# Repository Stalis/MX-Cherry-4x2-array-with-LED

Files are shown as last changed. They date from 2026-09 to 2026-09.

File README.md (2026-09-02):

# MX Cherry 4x2

## PCB Renders

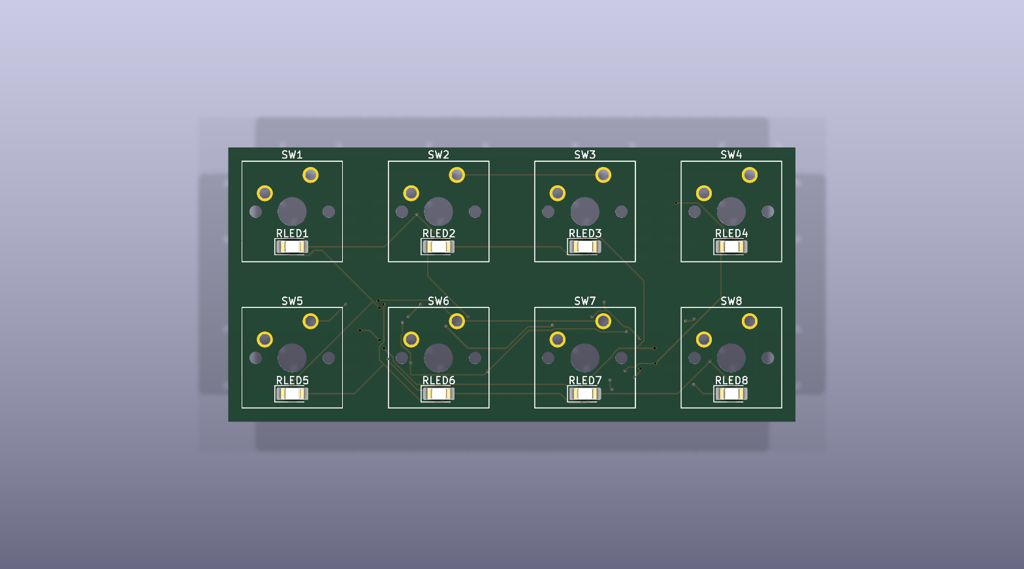
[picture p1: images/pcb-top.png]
Top-side PCB render

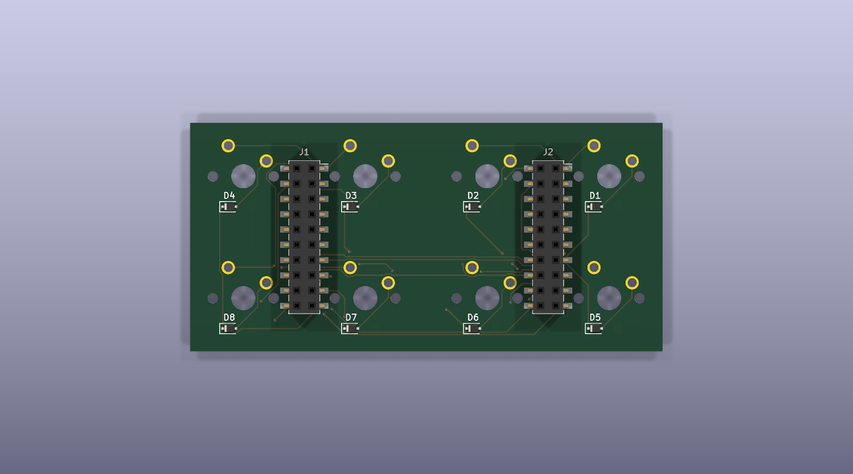
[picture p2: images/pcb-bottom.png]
Bottom-side PCB render


Compact 8-key Cherry MX keyboard module: 4 columns x 2 rows. It has no onboard microcontroller and is intended for connection to an external controller or breadboard.

## Features

- 8 Cherry MX 1U, PCB-mount switch footprints on a 19.05 mm pitch.
- 4x2 switch matrix with one diode per key.
- Independent 4x2 LED matrix with one LED per key.
- Two parallel SMD socket connectors, `J1` and `J2`: 2x10, 2.54 mm pitch, on the bottom side of the board.
- Two-layer, 1.6 mm thick PCB measuring 78.74 x 38.10 mm.

## Matrices

Key layout:

| | `COL_0` | `COL_1` | `COL_2` | `COL_3` |
| --- | --- | --- | --- | --- |
| `ROW_0` | SW1 / D1 / RLED1 | SW2 / D2 / RLED2 | SW3 / D3 / RLED3 | SW4 / D4 / RLED4 |
| `ROW_1` | SW5 / D5 / RLED5 | SW6 / D6 / RLED6 | SW7 / D7 / RLED7 | SW8 / D8 / RLED8 |

Each key has a series diode, `D1` through `D8`, to prevent ghosting during matrix scanning. LEDs `RLED1` through `RLED8` form an independent matrix with the same four columns and two rows.

## Connections

`J1` and `J2` are electrically identical: use either connector, or both to mount the module. Pin numbering follows the standard 2x10 connector convention: odd pins are on one row and even pins on the other.

| Pin | Signal | Function |
| --- | --- | --- |
| 1 | `SW_0_ROW_0` | switch-matrix row 0 |
| 2 | `LED_0_ROW_0` | LED-matrix row 0 |
| 3 | `SW_0_ROW_1` | switch-matrix row 1 |
| 4 | `LED_0_ROW_1` | LED-matrix row 1 |
| 5-12 | NC | not connected |
| 13 | `SW_0_COL_0` | switch-matrix column 0 |
| 14 | `LED_0_COL_0` | LED-matrix column 0 |
| 15 | `SW_0_COL_1` | switch-matrix column 1 |
| 16 | `LED_0_COL_1` | LED-matrix column 1 |
| 17 | `SW_0_COL_2` | switch-matrix column 2 |
| 18 | `LED_0_COL_2` | LED-matrix column 2 |
| 19 | `SW_0_COL_3` | switch-matrix column 3 |
| 20 | `LED_0_COL_3` | LED-matrix column 3 |

The controller must scan both matrices externally. The PCB has no LED current-limiting resistors; use an external current-limiting circuit or LED driver.

## Components

| Quantity | References | Footprint |
| --- | --- | --- |
| 8 | `SW1-SW8` | Cherry MX 1U, PCB mount |
| 8 | `D1-D8` | SOD-323F |
| 8 | `RLED1-RLED8` | LED 1206, 3216 Metric |
| 2 | `J1`, `J2` | SMD socket 2x10, 2.54 mm |

The schematic does not specify diode ratings or LED color and electrical parameters. Select them for the voltage and current of the external driver.

## DRC Notes

The following DRC findings are expected for this layout and should be excluded individually with a comment in KiCad after mechanical clearance is confirmed. Do not disable these checks globally.

| DRC check | Count | Rationale |
| --- | --- | --- |
| `npth_inside_courtyard` | 8 | The Cherry MX locating holes are through-holes, while `J1` and `J2` are bottom-side SMD connectors. The overlaps are courtyard-only; verify the connector body and pads clear the switch locating pins. |
| `courtyards_overlap` | 8 | Each top-side LED is intentionally placed at its associated switch for backlighting. |
| `footprint_symbol_field_mismatch` | 8 warnings | Diodes `D1-D8` have a schematic-only `Sim.Device` field that is absent from their footprints. This does not affect fabrication or electrical connectivity. |

## Repository Files

- `MX Cherry 4x2.kicad_pro` - KiCad project.
- `MX Cherry 4x2.kicad_sch` - main schematic.
- `MX Cherry 4x2.kicad_pcb` - PCB layout.
- `switch_module.kicad_sch` and `led_module.kicad_sch` - reusable sheets for one switch with a diode and one LED.
- `jlcpcb/` and `production/` - previously exported manufacturing files.

> The BOM and CPL files in `jlcpcb/` and `production/` are outdated relative to the current schematic and PCB. They omit `RLED1` through `RLED8` and describe the connectors as 1x10. Re-export Gerbers, BOM, and CPL from the current project before ordering.

## Opening and Checking

The project was created with KiCad 10. Open `MX Cherry 4x2.kicad_pro` in KiCad, or check it from the command line:

```sh
/Applications/KiCad/KiCad.app/Contents/MacOS/kicad-cli sch erc "MX Cherry 4x2.kicad_sch"
/Applications/KiCad/KiCad.app/Contents/MacOS/kicad-cli pcb drc --schematic-parity "MX Cherry 4x2.kicad_pcb"
```

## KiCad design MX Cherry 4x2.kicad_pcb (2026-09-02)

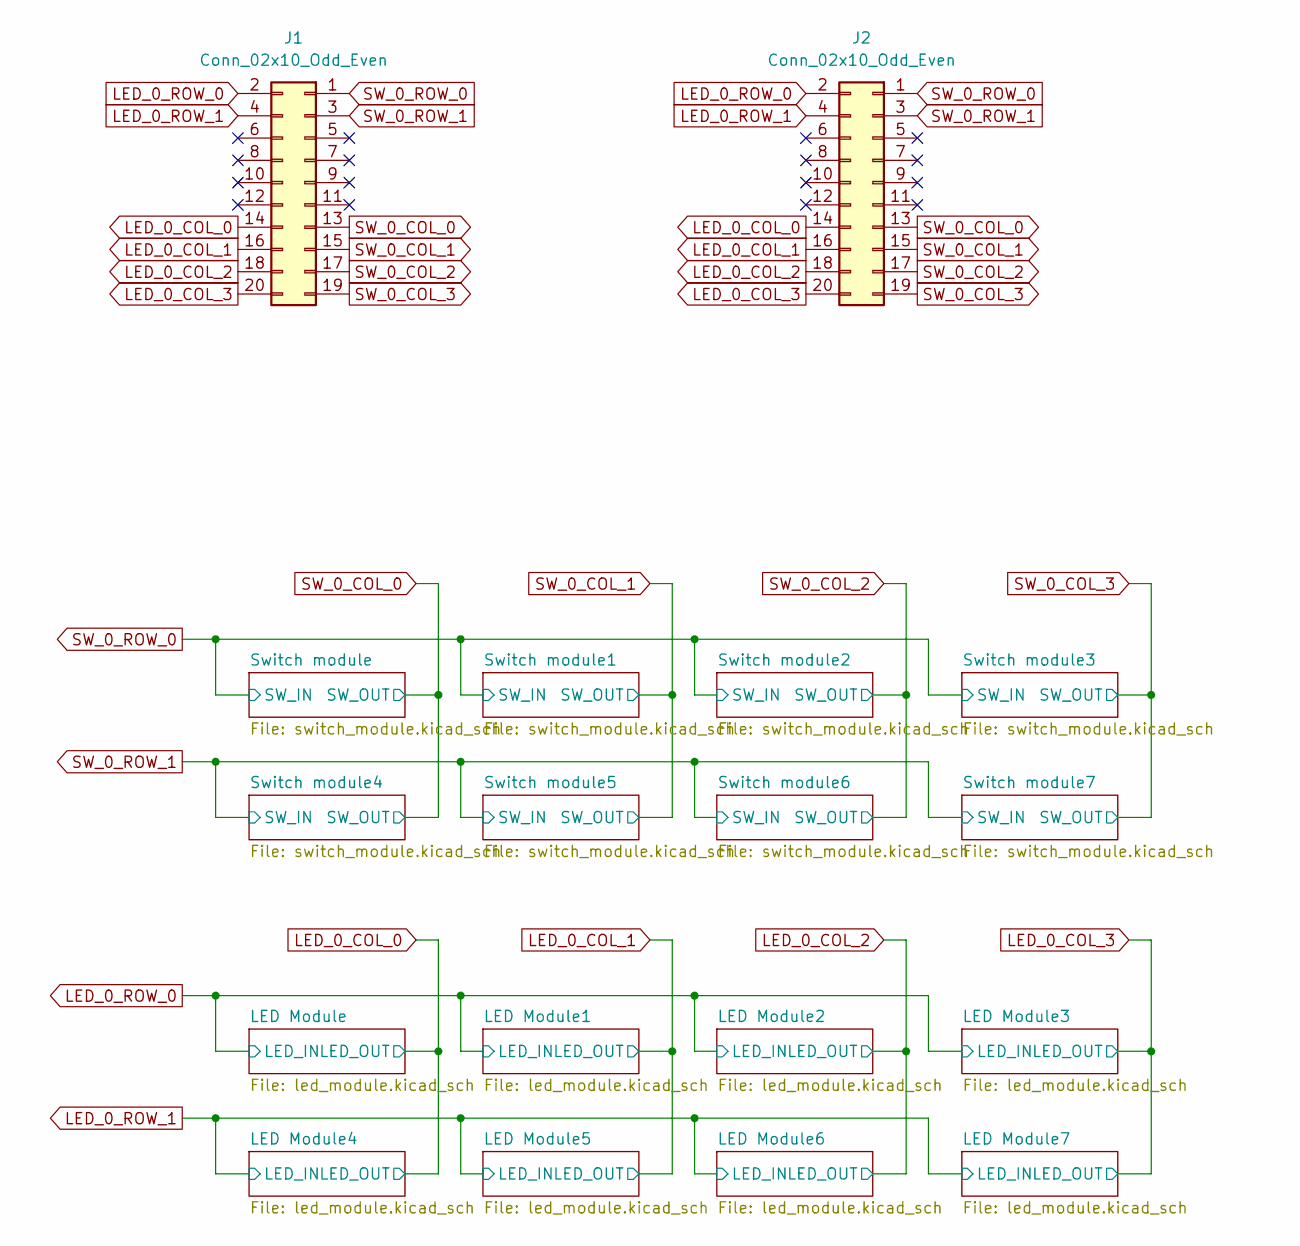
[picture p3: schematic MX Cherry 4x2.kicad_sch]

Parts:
J1, J2: Conn_02x10_Odd_Even; PinSocket_2x10_P2.54mm_Vertical_SMD

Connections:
LED_0_COL_0: J1.14, J2.14; also elsewhere on the board
LED_0_COL_1: J1.16, J2.16; also elsewhere on the board
LED_0_COL_2: J1.18, J2.18; also elsewhere on the board
LED_0_COL_3: J1.20, J2.20; also elsewhere on the board
LED_0_ROW_0: J1.2, J2.2; also elsewhere on the board
LED_0_ROW_1: J1.4, J2.4; also elsewhere on the board
SW_0_COL_0: J1.13, J2.13; also elsewhere on the board
SW_0_COL_1: J1.15, J2.15; also elsewhere on the board
SW_0_COL_2: J1.17, J2.17; also elsewhere on the board
SW_0_COL_3: J1.19, J2.19; also elsewhere on the board
SW_0_ROW_0: J1.1, J2.1; also elsewhere on the board
SW_0_ROW_1: J1.3, J2.3; also elsewhere on the board

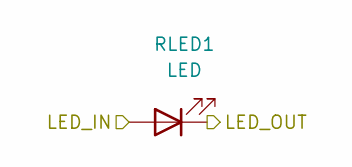
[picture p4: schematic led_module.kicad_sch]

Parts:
RLED1: LED; LED_1206_3216Metric_Pad1.42x1.75mm_HandSolder

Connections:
LED_0_COL_0: RLED1.1 (K); also elsewhere on the board
LED_0_ROW_0: RLED1.2 (A); also elsewhere on the board

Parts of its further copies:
RLED2, RLED3, RLED4, RLED5, RLED6, RLED7, RLED8: LED; LED_1206_3216Metric_Pad1.42x1.75mm_HandSolder

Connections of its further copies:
LED_0_COL_0: RLED5.1 (K); also elsewhere on the board
LED_0_COL_1: RLED2.1 (K), RLED6.1 (K); also elsewhere on the board
LED_0_COL_2: RLED3.1 (K), RLED7.1 (K); also elsewhere on the board
LED_0_COL_3: RLED4.1 (K), RLED8.1 (K); also elsewhere on the board
LED_0_ROW_0: RLED2.2 (A), RLED3.2 (A), RLED4.2 (A); also elsewhere on the board
LED_0_ROW_1: RLED5.2 (A), RLED6.2 (A), RLED7.2 (A), RLED8.2 (A); also elsewhere on the board

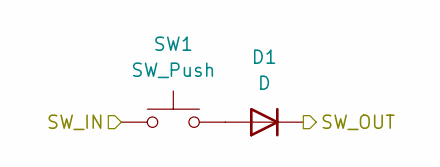
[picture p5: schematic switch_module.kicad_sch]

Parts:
D1: D; D_SOD-323F
SW1: SW_Push; SW_Cherry_MX_1.00u_PCB

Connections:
unnamed: D1.2 (A), SW1.2
SW_0_COL_0: D1.1 (K); also elsewhere on the board
SW_0_ROW_0: SW1.1; also elsewhere on the board

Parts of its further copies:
D2, D3, D4, D5, D6, D7, D8: D; D_SOD-323F
SW2, SW3, SW4, SW5, SW6, SW7, SW8: SW_Push; SW_Cherry_MX_1.00u_PCB

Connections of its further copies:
unnamed: D2.2 (A), SW2.2
unnamed: D3.2 (A), SW3.2
unnamed: D4.2 (A), SW4.2
unnamed: D5.2 (A), SW5.2
unnamed: D6.2 (A), SW6.2
unnamed: D7.2 (A), SW7.2
unnamed: D8.2 (A), SW8.2
SW_0_COL_0: D5.1 (K); also elsewhere on the board
SW_0_COL_1: D2.1 (K), D6.1 (K); also elsewhere on the board
SW_0_COL_2: D3.1 (K), D7.1 (K); also elsewhere on the board
SW_0_COL_3: D4.1 (K), D8.1 (K); also elsewhere on the board
SW_0_ROW_0: SW2.1, SW3.1, SW4.1; also elsewhere on the board
SW_0_ROW_1: SW5.1, SW6.1, SW7.1, SW8.1; also elsewhere on the board

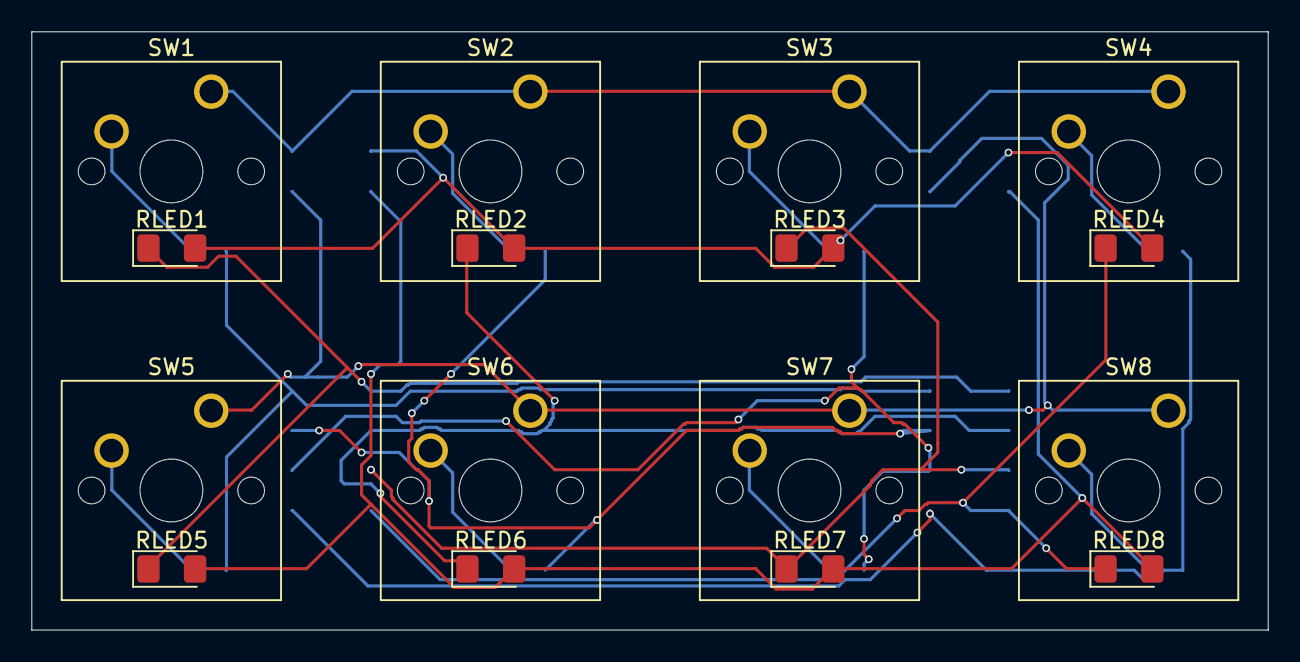
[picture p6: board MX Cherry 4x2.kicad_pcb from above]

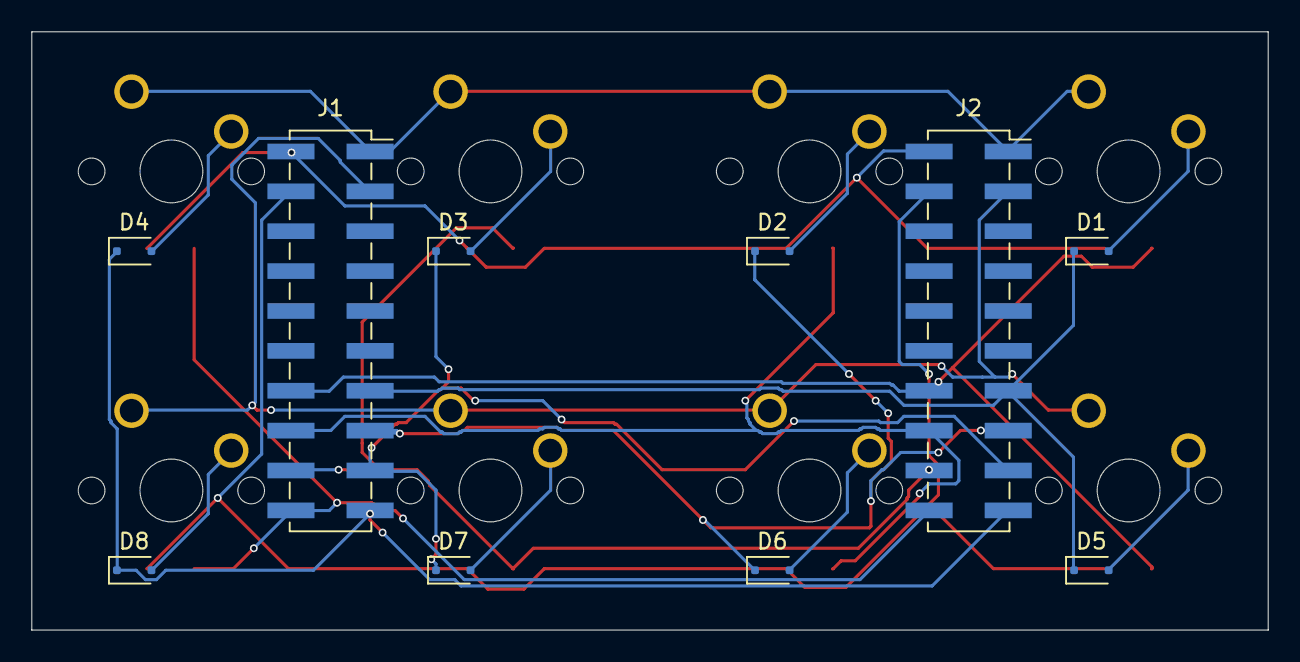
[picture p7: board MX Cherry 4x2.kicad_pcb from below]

Board: 2 copper layers, 78.7 x 38.1 mm, 26 parts (10 on the bottom side), 20 nets.

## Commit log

2026-09-02 Add LEDs
    [MX Cherry 4x2.kicad_pcb, MX Cherry 4x2.kicad_sch, led_module.kicad_sch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]
2026-09-02 Add PCB render images
